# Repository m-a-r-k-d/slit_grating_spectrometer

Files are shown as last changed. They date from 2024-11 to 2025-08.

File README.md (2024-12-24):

Building a slit spectrometer that uses a 300 line/mm grating. The goal is to perform stellar spectrometry at the focus of a small telescope. 

The project is based on the Sol'Ex project although Sol'Ex uses a reflection grating. I wanted to try to build one with a cheap transmission grating that can be found on Amazon or Ebay.

I'm trying to learn a little ray-tracing, so I've started to use Beam Four - an open source, Java-based ray-tracing program. I think that individuals can also use Zemax for free for a year, but I haven't tried that, yet.

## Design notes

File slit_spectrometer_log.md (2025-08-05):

Slit Spectrometer Project Log
====
The project is to build a slit spectrometer using a 300 lines/mm transmission grating and slit that I bought off of amazon for only $10 a piece. It will be based on the Sol'Ex spectrometer built by Christian Buil.
http://www.astrosurf.com/solex/sol-ex-presentation-en.html

**12-14-24**

Worked on understanding what the 3d print for the spectrometer will look like. I watched the YouTube video about putting together the Sol'Ex kit, and I downloaded the stl files. I do not know where to get step files ofr this or even if they're available. I might join one of the forums and ask about this.

One of the parts is printed with the very fine "telescope" threads. It's the "interface_tel_m42_#1.stl file.threads totally worked! I was surprised. Klipper does no allow '#' in a file name and I got an odd error from it, but I change # to num and it printed. NOTE: the kits sold by Azure3D use aluminum inserts instead of printed threads now.

The Sol'Ex has the ability to focus the collimator lens on the slit and also focus the camera lens. I think that I can use the same focus tube and lens mount that is used in that instrument for mine.

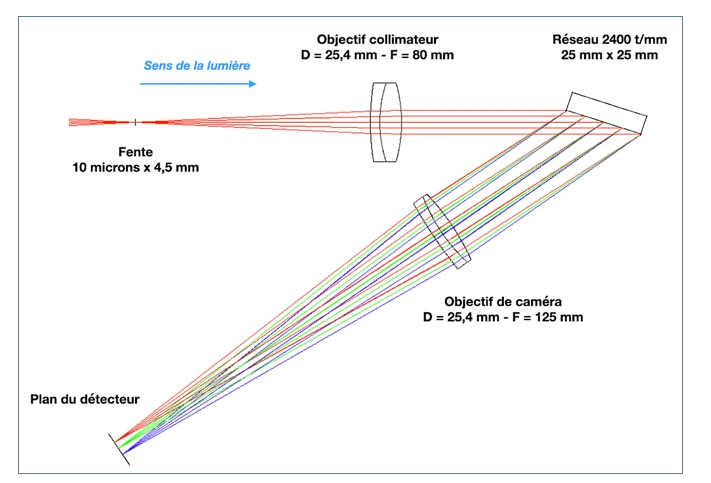
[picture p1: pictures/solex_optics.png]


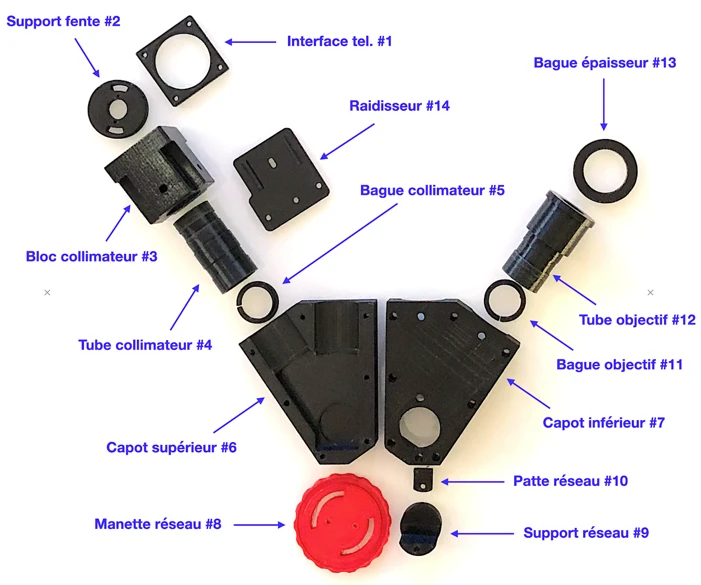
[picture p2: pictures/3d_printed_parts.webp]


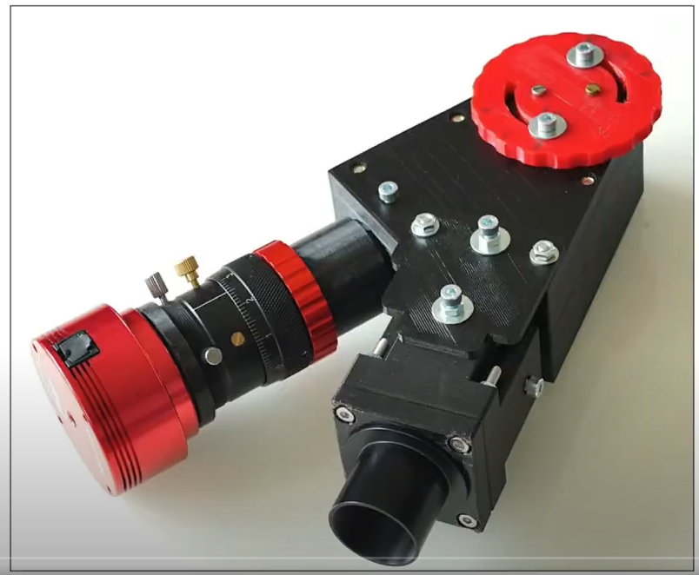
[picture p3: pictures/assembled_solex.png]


12-21-24 

Focusing the camera lens in the design of this spectrometer is more difficult that the Sol'Ex because the surplus lens I found for it is only 50mm focal length. It would be difficult to fit a helical focuser in this design look they do for the Sol'Ex. I'm designing a 3d printed focuser to do this. The idea is to use the tube-within-a-tube focuser design, but just use a screw to adjust the position - instead of a rack and pinion or other type of mechanism.

12-26-24

I've been re-designing parts for the spectrometer in Fusion starting from the .stl files that you can download. Instead of making the spectrometer a box with a top and bottom, it will be a tube. The design has a "diving board" that connects the main spectrometer to the collimator block. The diving board wasbolted to the box in the .stl files. I've incoprated it into the main tube. I've redesigned the collimator block to make it easier to print iwhtout supports.

I tried printing the diving board, and I've made changes to it. Not sure if I'll print that part again, or just go for the whole thing. Printing the collimator block now.

I need to figure out how to hold the slit in place. 
Design the grating holder.
Design the focus tube and the camera lens holder. I've already taken a first pass at the focuser, but it doesn't have a way to hold the lens.
Count up the hardware necessary, and put some on order.

12-29-24

I've been working on the camera lens and focus mechanism. I have a design for that mechanism. I've printed the inner and outer tubes. The inner tube does not fit still.
I put the camera lens into the Fusion model, so I think I have a good position for the focus. I want to verify that this focus position is correct using the QHY camera.

On the slit side, I put the collimator lens into the model. The focus is far away from where I thought it would be. I looked at the Sol'Ex optics and the collimator lens has an 80 mm focal length. 
This explains why the focus in  model is 20 mm off. The focus position for the surplus lens I have should be ~94mm from the face of the optic.
I've put a screen shot of the optics in the pictures at the beginning of this log for reference.

I'll have to redesign the collimator block to accomodate the new focus position.

12-30-24

Yesterday, I redesigned that collimator block I made it about an inch longer.

I tried a design of the camera lens/focuser assembly. I used a loft to connect the grating attachment to the focuser tube. I printed it in a way that needed supports. I don't like the results because the part that 
comes into contact with the lens is not flat (due to the supports). I think that I could redesign in a way that would allow me to print in the other orientation and eliminate the need for supports. This would also 
smooth out the lens mating surface. 

The focuser inner tube does not fit very snuggly in the outer tube so it jiggles a little. This might be a problem for stability of the focus position. Even with it a little loose, the screw/spring focus mechanism can bind.
This might also be a problem. I'd like to make the fit more snug. I think this focus adjustment will be set and forget, so it might still be usable. Concerned about the binding and the spring...

I need to be better about only using the assembly drawing for part positioning, and then use a separate file to design the individual part. 
The focuser/camera lens holder/grating interface is too complicated to design in the assembly drawing.
The timeline is useful to go back and change things but the timeline in the assembly drawing is so long that I can't find operations in irder to modify them. (8-4-25 Note: this is definitely true!)

8-4-25
Lots of developments that I did not track here. I made the spectrometer, and I pointed it out the window and I was able to see the fraunhofer lines in the sunlight. That was pretty cool.

Some highlights:
I did not use the focuser that I was talking about in the 12-30-24 log entry. I redesigned the focuser that I've used on a couple of telescopes. I used a 1 mm thread for it (I think).

I didn't make a holder for the slit. I just cut the slits out and mounted them under the two screws that would normally hold the mount for the slits. 

I made a little curcuit that will flash a neon lamp, and I used that to to calibrate the sprectometer. I need to make a similar one for the Ar lamp I bought.

I'm making a dovetail to support the telescope and the spectrometer. I had to print it in two parts since it needs to be almost two times the largest dimension of the printer.  Once the dovetail is printed, I can try testing the spectrometer on a star.

I bought a flip mirror which hopefully I can use for positioning a star on the slit. It also takes up a bunch of the focus distance, so I don't need a bunch of adapters.

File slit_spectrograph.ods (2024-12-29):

Playing with an achromat in Beam Four
Started with the ACHRO.OPT file using the GLASS.MED
Added SF2 and SF57 to the .MED file and called it ACHRO_mjd.MED
Used a uniform ray generator to make rays that only go out to 18mm even though the optic diameter is 30 mm
I used the C and the F wavelength for the rays.
I used BK7 (C=1.514323) for first optic and SF2 (1.64210) for the second
I set the focus position to 100 mm and then used AutoAdjust on the first and second curvatures to minimize the spot size
Then I removed the F rays from the .ray file, and ran autoAdjust but I only optimized the focus position. Z = 100.0139
Then I ran it for just the blue rays Z = 99.9862
Switched to SF57
Optimized the focus for 100 mm
Found focus position with red rays – Z=99.9467
Then found focus for blue rays – Z = 100.054
I’m giving up on designing an achromat. There are design numbers here: https://www.telescope-optics.net/semiapo_and_apo_examples.htm
R | Curv
62.8 | 0.015923566878981
-45.7 | -0.021881838074398
-128.2 | -0.007800312012481
300 lines/mm | 0.3
Whats the diffraction angle for yellow – 589 nm. I picked that because it’s close to 600 nm which is in the middle of the range I’d like to see, 400 to 800 nm
or maybe I’ll use 632.8nm
m | 1 |  |  | m | 1
groove | 300 | lines/mm |  | groove | 300 | lines/mm
groove spacing | 0.003333333333333 | mm |  | groove spacing | 0.003333333333333 | mm
lambda | 632.8 |  |  | lambda | 632.8
theta = | 10.9434469318732 |  |  | theta = | 10.9434469318732
Used coordinate breaks to deal with the angle change due to diffracttion
Spot size is huge!
Now for a blue beam
m | 1
groove | 300
groove spacing | 0.003333333333333
lambda | 404.7
theta = | 6.9734846670423
If I allow B4 to change the pitch of the coordinate break, it will find the diffraction angle. Which is pretty cool.
However, if I set the diffraction angle/coordinate break to 10.9 – for 632nm – and then keep it fixed, import the blue .ray file.
And then AutoAdjust to find the focus position for xfinal and yfinal (=0), the final surface position moves much closer to the camera lens.
I don’t understand why that happens.
This is what it looks like with both read and blue beams and the pitch set to 10.9 degrees – the diffraction angle for 632 nm
There’s some vignetting on the blue beam
I could zoom in and just manually determine the focus position of the red and blue beams. This would give me the angle of the focal plane
I’m re-doing the .OPT file so that it has a diverging beam as the source instead of an achromat telescope. The telescope’s aberations will complicate the ray trace.
diam = | 25.4
f = | 100.1
f# = | 3.94094488188976
eng_diam = | 20
f = | 100.1
f# = | 5.005
Direction cosine
cos= | 0.099405297447666
Ok, I found a good way to set the first lens position to collimate. I used a “point” source that I made using a circular arry of rays that is 0.1mm.
I constructed the .OPT file so that there is a mirror to retro the beam back to the focus.
I’m only using 9 surfaces in the .OPT file below, and it goes from the retro mirror back through the lens. The “films” surface is back at Z=0
AutoAdjust on the Lens position(s) – marked with the ‘a’.
For xgoal and ygoal, I put in the starting locations, X0 and Y0.
Now I can use that focal distance and leave the first lens (the collimator) in position, and add in the grating and the “camera” lens.
This is much better collimated. You can see that from the U5 and V5 angles in the .ray file. They are all 0.0.
I put in the camera lens but with no grating.
Now, I’ll put in the grating.
I have to make sure it will fit on the detector of my camera now. I might need to change the grating to camera lens distance.
Found a 25mm diameter 50 mm focal length lens. Here are the Thorlabs curvatures
R | Curv
33.3 | 0.03003003003003
-22.3 | -0.044843049327354
-291.1 | -0.003435245620062
There’s a 25.4mm f=50mm achromat on ebay for $15. It’s BK7 and SF2. It’s an optisugma part, but I can’t find curvature data on it.
I put the Thorlabs one in the model:
The 50mm focal length gets the blue to red distance down so that the spectrum from 0.4 to 0.7 um will fit on the sensor.
I need to center it better though
The blue spot is 0.4047 um
The red is 0.706 um
The distance between them is
wavelength | position
0.4047 | -3.34
0.706 | 1.13
0.3013 | 4.47
0.15065 | 2.235
0.55535
The closest wavelength that I have Schott index data for is 0.548 um – the e-line
Added that wavelength to the .MED file.
I’m going to find the focus position for the three wavelengths.
 |  | X | Y
0.4047 | 243.6233 | 0.6233 | -2.16
0.546 | 243 | 0 | 0
0.706 | 242.8295 | -0.170500000000004 | 2.42
 | x-intercept = | 0.16777
Adjusting the pitch of the film surface by eye, it looks like 10 degrees (ccw) will balance the spot sizes from 0.4 to 0.7 um
Using the trendline and the x intercept, I can get more uniform spot size from red to blue.
Use a rotation of the detector plane of 10.99 deg and offset the focus point by +0.168mm
What’s the distance between the spots along the plane of the detector?
m= | -5.148979
y-int = | 0.86382
 | X | Y
0.4047 | 0.59 | -2.17407761
0.706 | -0.3 | 2.4085137
distance (mm) = | 4.66821626689333
The detector is 5.6mm x 3.2mm
Here’s the ZEMAX info for the collimator lens I got from Surplus shed: Melles Griot P/N 01LAO123
DBDT 0 LAO123 100.0200 26.5000
DBDT 1 2 0 0 0 0 0
NAME LAO123 PRECISION OPTIMIZED ACHROMATS
ENPD 23.850
GCAT SCHOTT OLD_SCHO MISC
WAVL .4861 .5876 .6563
PWAV 2
SURF
CURV 0
DISZ INFINITY
SURF
COMM LAO123
STOP
CURV 0.015615
DISZ 4.800000
GLAS SK11
DIAM 13.250000 1 0
SURF
CURV -0.022282
DISZ 2.000000
GLAS SF5
DIAM 13.250000 1 0
SURF
CURV -0.005473
MAZH 0 0
DIAM 13.250000 1 0
SURF
VERS 0
I’m making a new spectrograph model for the two new optics.
Starting with the melles griot collimator optic. I’m determining the position of the focus point.
The optical model is SPECTRO3_collimation.OPT. This is the optic and a mirror.
I’m going to find the focus position for the blue, red and center wavelengths
I changed the rays in the .ray file so that they emanate from a spot 25 um in diameter. It was 100 um
There are four .ray files for the blue, center, red, and all three conmbined.
wavelength | S2_focus_pos | S3_focus | S4_focus
0.4047 | 96.9897 | 98.9897 | 103.7897
0.4861 | 96.4852 | 98.4852 | 103.2852
0.4358 | 96.7046 | 98.7046 | 103.5046
0.546 | 96.3965 | 98.3965 | 103.1965
0.6563 | 96.4144 | 98.4144 | 103.2144
0.706 | 96.4607 | 98.4607 | 103.2607
C (656.3) | 96.4144 | 98.4144 | 103.2144 | Is the difference in focus position between C and F good? I think these are the wavelengths that an achromat shoyuld correct for.
F (486.1) | 96.4852 | 98.4852 | 103.2852
170.2
160
I’m going to put the collimating lens at an “inbetween” position, Z = 96.45
I’ll do the same study of the focus position for the camera lens
DLB-25.4-50PM
wavelength | S2_focus_pos | S3_focus | S4_focus
0.4047 | 44.7026 | 47.2026 | 55.6026
0.4358 | 44.5769 | 47.0769 | 55.4769
0.4861 | 44.4927 | 46.9927 | 55.3927
0.546 | 44.4724 | 46.9724 | 55.3724
0.6563 | 44.5097 | 47.0097 | 55.4097
0.706 | 44.5378 | 47.0378 | 55.4378
This seems better corrected than the collimator lens.
Z = 44.5 mm, looks like a good focus distance
I think that I should limit the design wavelengths to 435 to 700 nm. That’s where the lenses are best corrected.
Not sure if I should change the design to optimally fit that wavelength range onto the detector…
Koby said that I should image the entrance pupil of the telescope on the grating.
If I’m using the new fancy refractor ED72, the focall length is 420 mm
telescope | focal length | object | image | 1/f | 1/object | 1/image
ED72 | 96.45 | 420 | 125.201668984701 | 0.010368066355625 | 0.002380952380952 | 0.007987113974672
Omni 6” | 96.45 | 750 | 110.683956851044 | 0.010368066355625 | 0.001333333333333 | 0.009034733022291
Mak Cas | 96.45 | 1300 | 104.179302895601 | 0.010368066355625 | 0.000769230769231 | 0.009598835586394
The grating should be 125mm from the collimation lens.
For the collimation lens the position of the surfaces will be
surface 1 | surface 2 | surface3
96.45 | 98.45 | 103.25
For camera lens:
surface 1 | surface 2 | surface3 | focus position
243 | 251.4 | 253.9 | 298.4
ray file: SPECTRO3_25um_src_single_wavelength.ray
opt file: SPECTRO3_grating_real_lenses.OPT
glass_mjd.med
I added PET to the list of materials since that’s what the grating is made of
I used AutoAdjust to find the angle of difraction for the 0.546 um rays
diffraction angle = | 9.4288
Now putting three wavelengths through the system: 0.4358 (g line), 0.546 (e-line), 0.706 (r-line)
wavelength | focus position(mm) | x position (mm)
0.4047 | 298.5438 | -2.133
0.4358 | 298.4246 | -1.661
0.546 | 298.3614 | 0
0.706 | 298.3348 | 2.44
 |  |  |  |  |  |  | 124.75
The focal plane Z=298.39mm
The focal plane should be tilted by 3.1 degrees
The slit long axis is parallel to the grating grooves.
The beam is 20mm at the grating, so it is pretty close to getting clipped by the grating holder.
It will be +/-1.5 mm for a beam on axis. For the slit there will be vignetting on the grating, I think.
What’s the “resolution” or wavelength per pixel?
IMX462 sensor:
QHY5III462M
5.6 mm x 3.2 mm
1920 x 1080
pixels/mm | 342.857142857143
The vertical distance between 404.7nm abd 706nm is 2.3 + 2.0 mm = 4.3 mm
wavelength/mm = | 70.0697674418605
wavelength/pixel = | 0.20437015503876
BUT, the slit I will use is 50 um so I’ll actually be imaging that slit, so I think the wavelength resolution will be dominated by the image of the slit.
The collimator and camera lens focal lengths will make the slit reduced in size by a factor of 2.
50 um slit will be imaged as 25 um.
pixels across the slit: | 8.62068965517241
The spot is rectangular/square. I think this is just the way that Beam4 makes the rays:
The following is 2D plot of a large number of rays at the surfae of the camera optic.
X0 | Y0
0 | 0
0.011 | 0.0062
0 | 0.0125
-0.011 | 0.0062
-0.011 | -0.0063
0 | -0.0125
0.011 | -0.0063
0 | 0
0.011 | 0.0062
0 | 0.0125
-0.011 | 0.0062
-0.011 | -0.0063
0 | -0.0125
0.011 | -0.0063
collimator lens (LAO123)
 | curvature (1/mm) | R (mm)
surface1 | 0.005473 | 182.715147085693
surface2 | 0.022282 | 44.87927475092
surface3 | -0.015615 | -64.040986231188
camera lens
 | curvature (1/mm) | R (mm)
surface1 | 0.030769 | 32.5002437518281
surface2 | -0.0449539 | -22.2450110001579
surface3 | -0.016286645 | -61.3999998158
12-17-24
I’m concerned that the 0 order (i.e. straight through beam) is going to cause problems.
I opened the spectrometer optical model and set the grating mm/line setting to 0. The wavelength is 546 nm
I think that the lens will put the image of the straight through beam off the detector.
maybe that will be ok. or I could move the camera lens away from the grating so that the zero order beam won’t go through the aperture.
Another concern is that it would be nice to have a focuser for the camera lens but there is only 50-55 mm between the lens and the detector.
I could redesign the 3D printed focuser to work maybe? I know I can make finer threads, and this focuser only needs to move through maybe 10 mm at most.
12-21-24
designed the tubes for a possible camera lens focuser. Printing the inner tube now.
The Fusion file is “spectro_focuser”
It needs a raft since it’s tall without very much surface area in contact with the bed. I had one attempt lose contact and had to abort it.
dimensions of the grating slide:
4.28915332881902
9.01
7.7

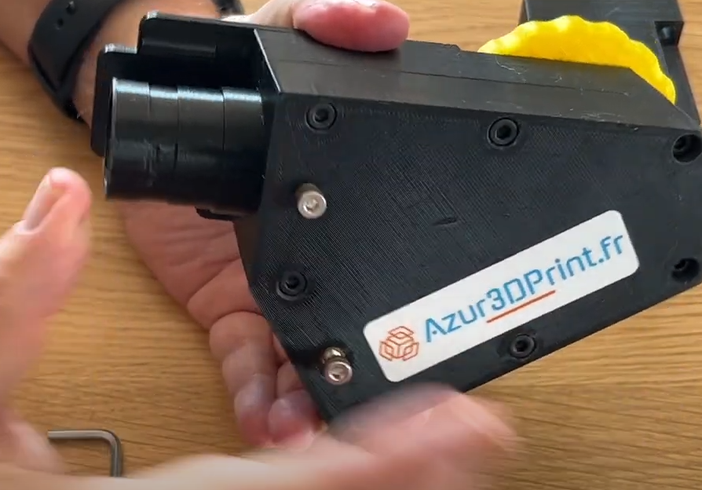
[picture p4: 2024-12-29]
pictures/collimator_tube_mounting_on_spectro_body_2.png

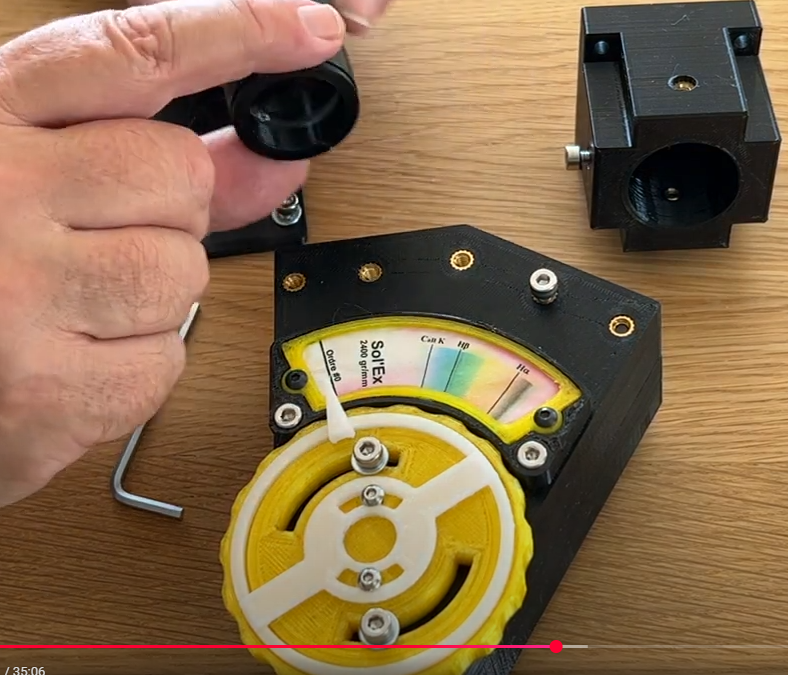
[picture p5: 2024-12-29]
pictures/collimator_tube_mounting_on_spectro_body.png

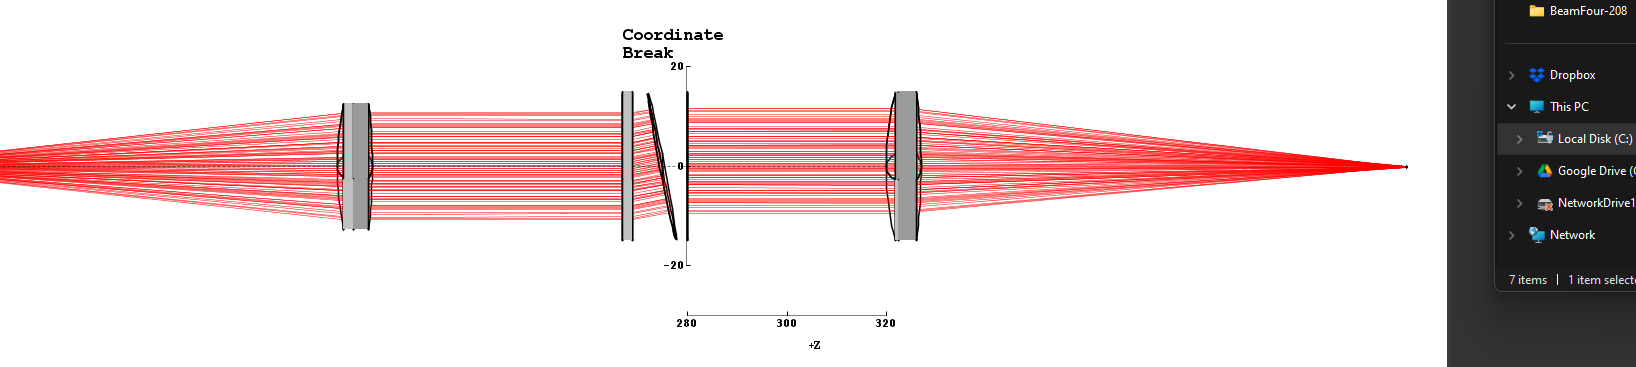
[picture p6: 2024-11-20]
Quick2.png

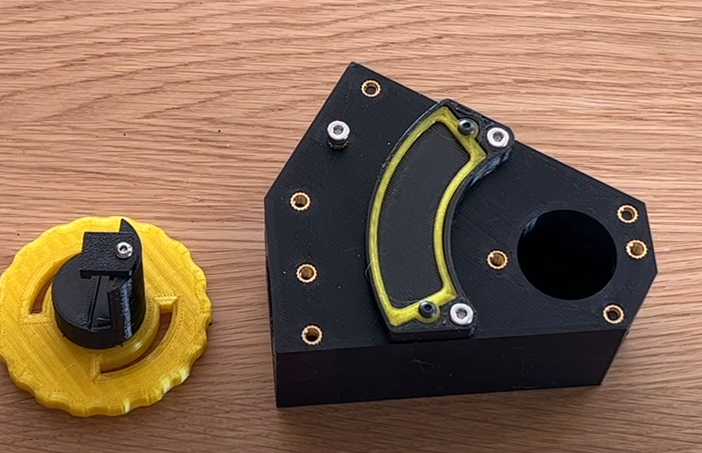
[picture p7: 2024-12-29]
pictures/solex_top_showing_inserts.png

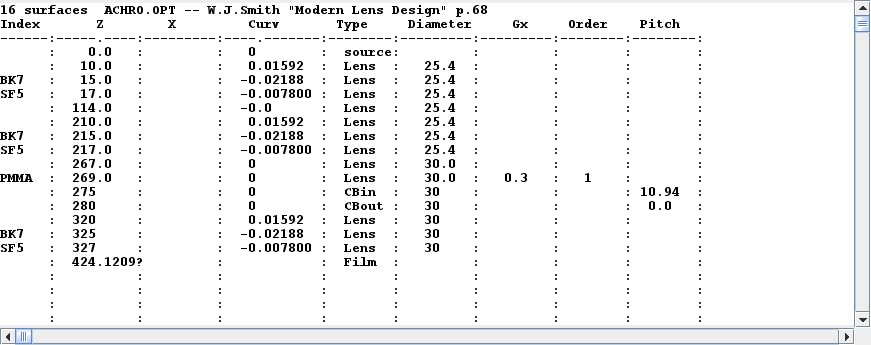
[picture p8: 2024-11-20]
Quick1.png

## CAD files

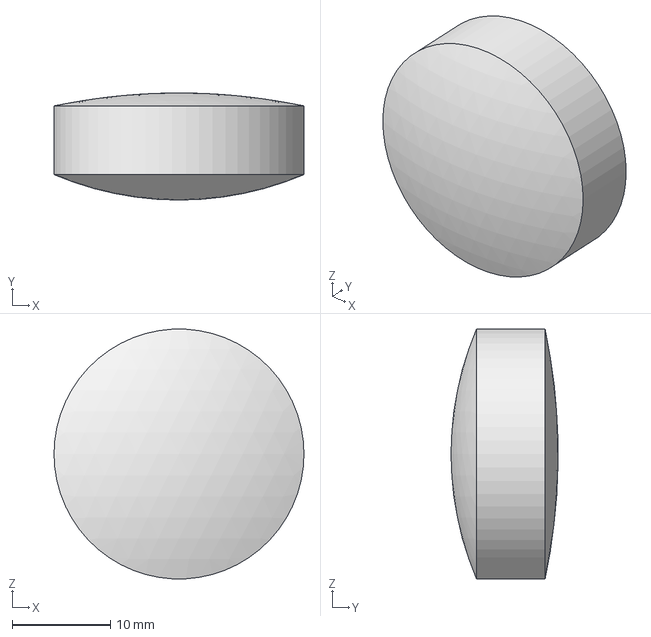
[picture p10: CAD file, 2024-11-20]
ray_trace/optic_files/camera lens/DLB-25.4-50PM_STP/DLB-25.4-50PM.stp
25.4 x 10.9 x 25.4 mm

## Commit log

2024-11-20 First commit.
    [slit_spectrograph.ods]
2024-11-20 Adding optic files for the 50mm focal length optic used as camera lens.
    [DLB-25.4-50PM.stp]
2024-11-23 Adding some Zemax files for the lenses.
    [DLB-25.4-50PM.stp, slit_spectrograph.ods]
2024-11-28 Designed the spectrometer using the lenses that I bought. I think I can start making the model for the 3D print.
    [slit_spectrograph.ods]
2024-12-18 Adding a log file and changes to the notes spreadsheet.
    [slit_spectrograph.ods]
2024-12-18 Changes to log.
    [slit_spectrograph.ods]
2024-12-24 Assembled Sol'ex picture
2024-12-29 ADded some pictures of how the Sol'Ex goes together. Update to the log.
    [slit_spectrograph.ods]
